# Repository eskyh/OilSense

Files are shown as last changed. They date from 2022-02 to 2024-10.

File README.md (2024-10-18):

## Home Cloud-based Smart Heating Oil Monitoring and Ordering Decision System

This project developed a smart IoT system that combines a **Raspberry Pi Zero** as the central home cloud server (Running **Node-RED** and **MQTT** broker) with distributed smart **ultrasonic sensors** (based on the **D1 Mini-ESP8266**) to monitor home heating oil levels. The system sends alerts to your phone when oil levels drop below a set threshold and features **one-button oil ordering** from the best available deal in the marketplace. This star architecture can be easily extended to other smart home applications, such as sump pit water level monitoring, as shown in Figure 1.

                                            **Figure 1. System architecture**   

System Architecture

## 1. Dashboard and Node-RED Workflow

The Node-RED data flows consist of two components outlined below. They are rendered as dashboards that are accessible on your phone from anywhere (**NOTE**: Port forwarding needs to be configured in the home router!).

1. **Oil Level Monitoring**: This includes oil level monitoring, data management, and dashboard functionalities. Check out the dashboard demonstration in Figure 2 and the simplified worflow (for convenience of demonstration) behind the scene in Figure 4 and 5.

2. **Oil Marketplace and Ordering**: This covers the oil price marketplace and ordering functionalities. See the dashboard demonstration in Figure 3 and the simplified workflow behind the scene in Figure 6.

                           **Figure 2. Oil level monitoring dashboard.**

Oil level monitoring dashboard

                                    **Figure 3. Oil Marketplace and ordering dashboard**

Heating oil marketplace and ordering dashboard

                    **Figure 4. Sensor data processing workflow in Node-RED**

Sensor data processing workflow in Node-RED

`1. Receive sensor measurement data messages from the subscribed MQTT broker.`
`2. Apply filtering algorithms (Median, Kalman Filter, and EWMA) to the measurements.`
`3. Calculate the heating oil level in the tank based on the distance measured from the top of the tank to the oil surface.`
`4. Only pass messages if the change in measurement exceeds a specified threshold.`
`5. Display the oil level and historical data, including daily consumption, on the dashboard.`
`6. Save oil level data to a file.`
`7. Trigger an alarm and send a notification to mobile devices via Telegram bot.`
`8. Toggle notifications on or off via Telegram messages or from the dashboard on mobile.`
`9. Display diagnostic information and environmental data (temperature and humidity) on the dashboard.`

                                            **Figure 5. Actuator workflow in Node-RED**
Actuator workflow in Node-RED

`1. Receive heartbeat, commands, and information messages from the subscribed MQTT broker.`
`2. Display configuration controls for MCU devices (e.g., toggle LED on/off, enable/disable automatic measurement, set measurement intervals, select data filters, enable/disable sensors, trigger a one-time measurement, restart the smart sensor, etc.`
`3. Publish configuration options as retained messages to the MQTT broker, so all subscribed smart sensors will automatically configure themselves based on these settings.`
`4. Publish acturator MQTT messages, so all subscribed smart sensors will execute the corresponding actions.`

                                            **Figure 6. Marketplace workflow in Node-RED**
Marketplace workflow in Node-RED

`1. Collect the real-time futures data.`
`2. Collect real-time local marketplace quotes.`
`3. Dashboard controls and charts showing prices.`
`4. Same as 2 but for another city.`
`5. Set order type (cash/credit) and order amount.`
`6. Construct order with preset form fields and placing order.`

## 2. Source Code Structure

[**`/gauge/src/`**](https://github.com/eskyh/OilSense/tree/main/gauge/src)

[`main.cpp`](https://github.com/eskyh/OilSense/tree/main/gauge/src/main.cpp): The main function of **D1 Mini (ESP8266)** microcontroller firmware. It calls `EspClient` class to do the following works:

`setup()` : Executed once at the start of the program, this phase is typically used for configuration and hardware initialization. Invoke `EspClient::setup()` to load configurations, establish WiFi/MQTT/OTA connections, initialize sensors, and sync time with the NTP server.

`loop()` : Executed repeatedly (hence the name 'loop'). Invoke `EspClient::loop()` to do sensor measurements, MQTT subscribing/publishing messages, processing MQTT actuator commands, managing the web portal, uploading firmware via WiFi, and restarting the device.

[**`/myLibs/network/`**](https://github.com/eskyh/OilSense/tree/main/myLibs/network)

[`EspClient.hpp`](https://github.com/eskyh/OilSense/tree/main/myLibs/network/EspClient.hpp), [`EspClient.cpp`](https://github.com/eskyh/OilSense/tree/main/myLibs/network/EspClient.cpp): The primary class responsible for managing all functions in the firmware and is designed as a singleton.

[`JTimer.h`](https://github.com/eskyh/OilSense/tree/main/myLibs/network/JTimer.h), [`JTimer.cpp`](https://github.com/eskyh/OilSense/tree/main/myLibs/network/JTimer.cpp): Designed to provide an efficient timing mechanism within the firmware. It simplifies the management of timed events and callbacks and is designed as a singleton.

[`Config.hpp`](https://github.com/eskyh/OilSense/tree/main/myLibs/network/Config.hpp), [`Config.cpp`](https://github.com/eskyh/OilSense/tree/main/myLibs/network/Config.cpp) : Managing configuration settings in a JSON format.

EspClient class diagram

JTimer class diagram

[**`/myLibs/sensors/`**](https://github.com/eskyh/OilSense/tree/main/myLibs/sensors)

[`sensor.hpp`](https://github.com/eskyh/OilSense/tree/main/myLibs/sensors/sensor.hpp), [`sensor.cpp`](https://github.com/eskyh/OilSense/tree/main/myLibs/sensors/sensor.cpp): The base **Sensor** calss for other derived sensors below:

- [`sr04.hpp`](https://github.com/eskyh/OilSense/tree/main/myLibs/sensors/sr04.hpp), [`sr04.cpp`](https://github.com/eskyh/OilSense/tree/main/myLibs/sensors/sr04.cpp): Ultrasonic range sensor class for the HC-SR04.

- [`dht11.hpp`](https://github.com/eskyh/OilSense/tree/main/myLibs/sensors/dht11.hpp), [`dht11.cpp`](https://github.com/eskyh/OilSense/tree/main/myLibs/sensors/dht11.cpp): Temperature and humidity sensor class for DHT11.

- [`vl53l0x.hpp`](https://github.com/eskyh/OilSense/tree/main/myLibs/sensors/vl53l0x.hpp), [`vl53l0x.cpp`](https://github.com/eskyh/OilSense/tree/main/myLibs/sensors/vl53l0x.cpp): Infrared distance sensor class for VL53L0X.

[`filter.hpp`](https://github.com/eskyh/OilSense/tree/main/myLibs/sensors/filter.hpp), [`filter.cpp`](https://github.com/eskyh/OilSense/tree/main/myLibs/sensors/filter.cpp): Data filtering algorithm classes: **Median**, **Kalman**, **EWMA**.

[`band.hpp`](https://github.com/eskyh/OilSense/tree/main/myLibs/sensors/band.hpp), [`band.cpp`](https://github.com/eskyh/OilSense/tree/main/myLibs/sensors/band.cpp):  Band filter class supporting both dead band and narrow band.

The **`Sensor`** base class encapsulates common functionalities shared across all sensor types, such as:

* `_read()`: A pure virtual function that each derived sensor class implements to handle sensor-specific reading logic.  
* `setFilter()`: Allows the assignment of a filter (e.g., Median, Kalman, EWMA) to process sensor data.  
* `setMqtt()`: Set MQTT client for data transmission.  
* `getPayload()`: A pure virtual function that is implemented by each derived class to format the sensor's data for transmission.  
* `sendMeasure()`: A method that handles data communication or publication to an MQTT broker or other destinations.

Sensor class diagram

[**`/gauge/web/`**](https://github.com/eskyh/OilSense/tree/main/gauge/web)

[`main.html`](https://github.com/eskyh/OilSense/tree/main/gauge/web/main.html) : A lightweight, all-in-one web portal developed for smart sensor management on D1 Mini. Users can configure settings and perform firmware upgrades over Wi-Fi. This file relies on the following JavaScript and CSS code.

[`espman.js`](https://github.com/eskyh/OilSense/tree/main/gauge/web/espman.js) :  JavaScript code provides the following functions for the web portal: AJAX-based retrieving/updating smart sensor configuration using JSON, adding/removing sensors, pin configurations, file management, firmware uploads, and device restarts.

[`filedrag.js`](https://github.com/eskyh/OilSense/tree/main/gauge/web/filedrag.js) :JavaScript code enabling drag-and-drop functionality on the *File Management* page of the web portal.

[`style.css`](https://github.com/eskyh/OilSense/tree/main/gauge/web/style.css) : The stylesheet for the web portal.

[`release.bat`](https://github.com/eskyh/OilSense/tree/main/gauge/web/release.bat) : A batch command file compresses the `main.html` and all supporting script files into a single HTML, then gzips it. This significantly improves web portal access performance.

[`/config/`](https://github.com/eskyh/OilSense/tree/main/gauge/web/config) :  This subfolder contains three sample configuration JSON files.

                                    **Figure 7. Web portal for Microcontroller**

Web portal for smart sensor

[**`/tools/`**](https://github.com/eskyh/OilSense/tree/main/tools)

[`index.html`](https://github.com/eskyh/OilSense/tree/main/tools/index.html): A web-based tool I developed to display multi-time series data (e.g., oil level data from `data.series.csv`) or marketplace quotes from various dealers (e.g., `data.quotes.csv` as shown below).

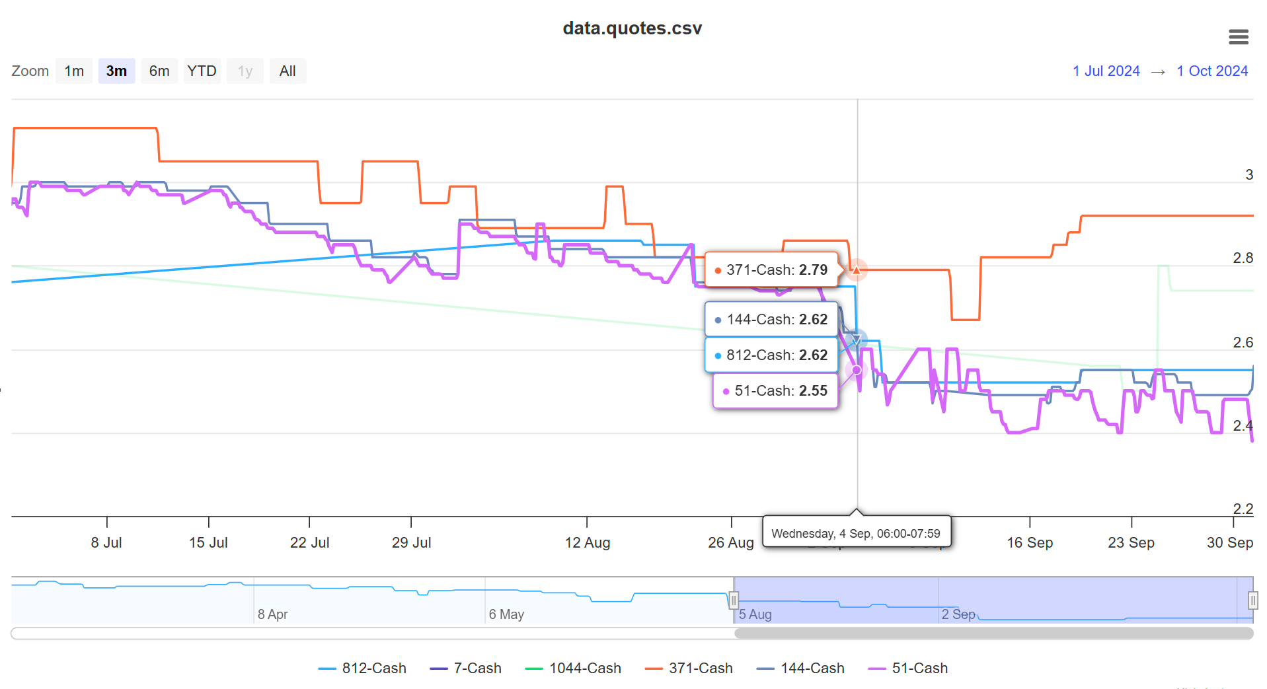
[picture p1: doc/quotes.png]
Marketplace quotes chart


[**`/gauge/3d_model/`**](https://github.com/eskyh/OilSense/tree/main/gauge/3d_model)

A series of 3D model of internal structural components designed to support the D1 Mini and connected sensors. `model_final_subtract.3mf` is the final design, while the others are either intermediate versions or older designs where the sensor seat location caused interference with the housing.

3D design model

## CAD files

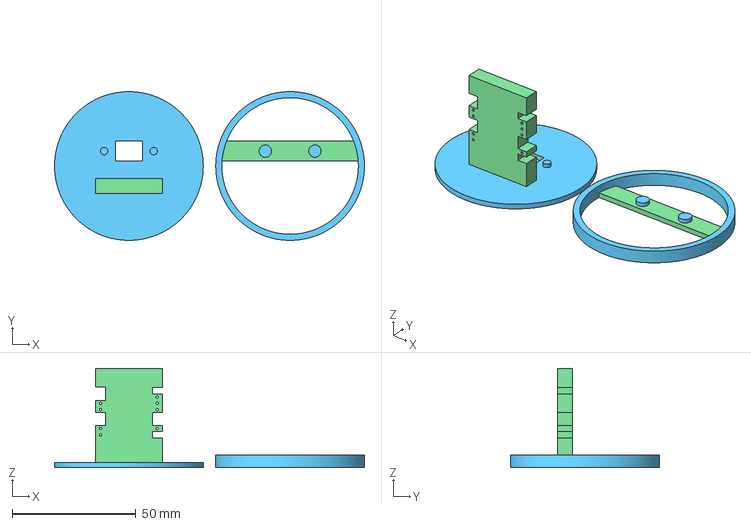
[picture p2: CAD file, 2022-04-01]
gauge/3d_model/model_laser_subtracted.3mf
125.0 x 60.0 x 40.0 mm

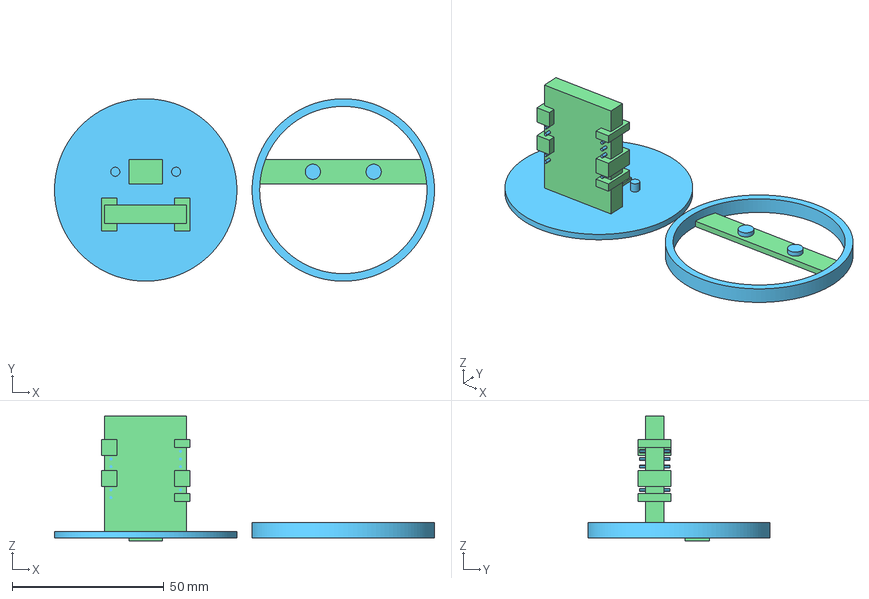
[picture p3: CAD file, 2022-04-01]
gauge/3d_model/model_laser.3mf
125.0 x 60.0 x 41.0 mm

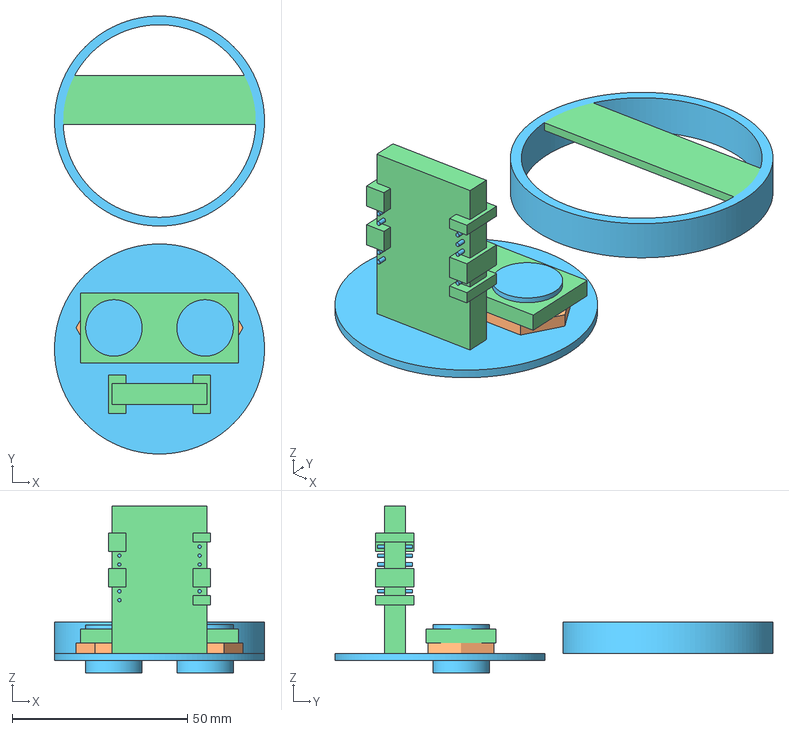
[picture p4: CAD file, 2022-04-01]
gauge/3d_model/model_final.3mf
59.9 x 124.9 x 47.5 mm

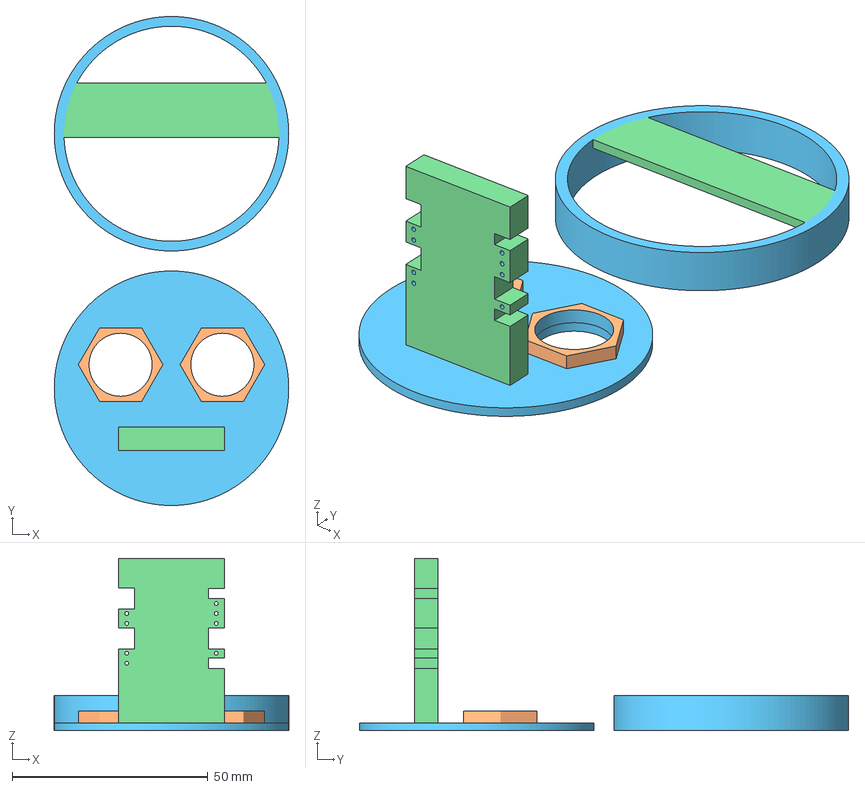
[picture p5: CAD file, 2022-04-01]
gauge/3d_model/model_final_subtract.3mf
59.9 x 124.9 x 44.0 mm

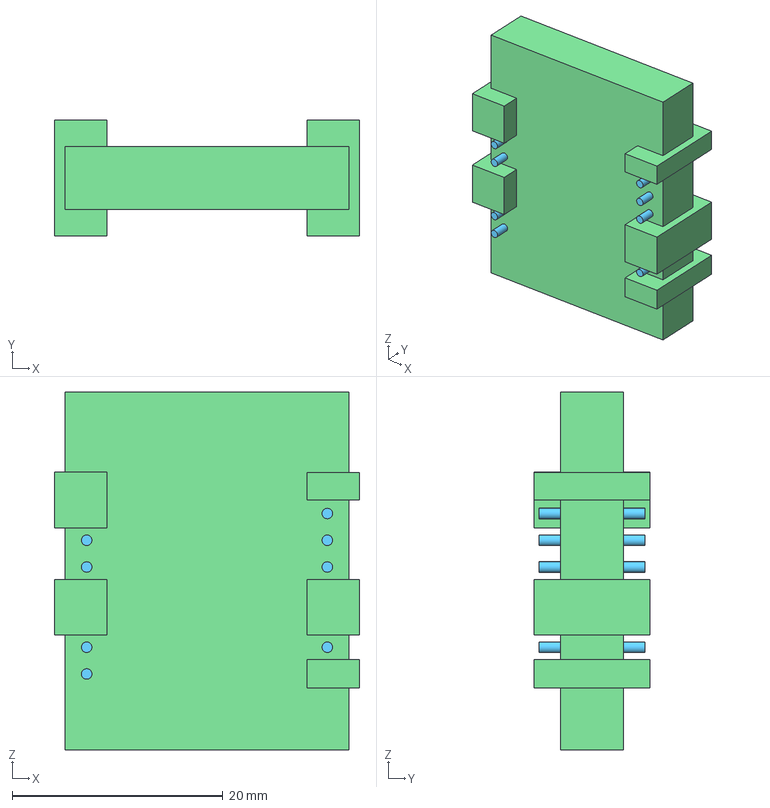
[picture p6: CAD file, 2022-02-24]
gauge/3d_model/breadboard.3mf
29.0 x 11.0 x 34.0 mm

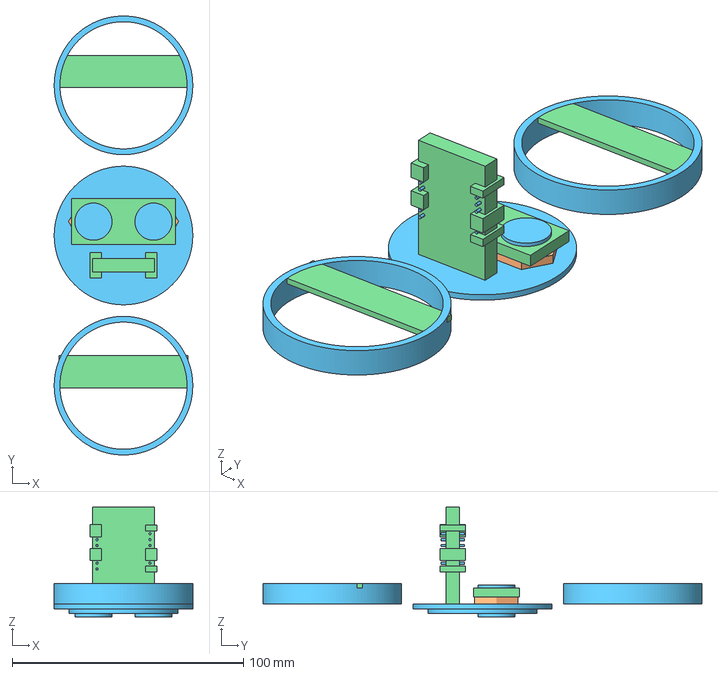
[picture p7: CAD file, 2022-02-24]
gauge/3d_model/model.3mf
60.0 x 190.0 x 47.5 mm

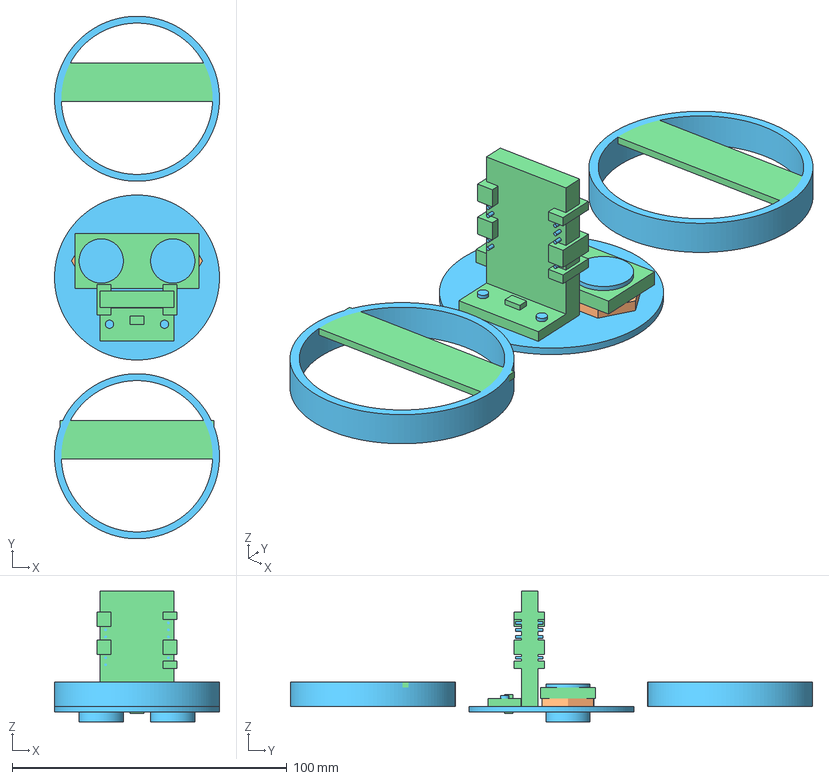
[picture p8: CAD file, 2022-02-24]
gauge/3d_model/model_dual.3mf
60.0 x 190.0 x 47.5 mm

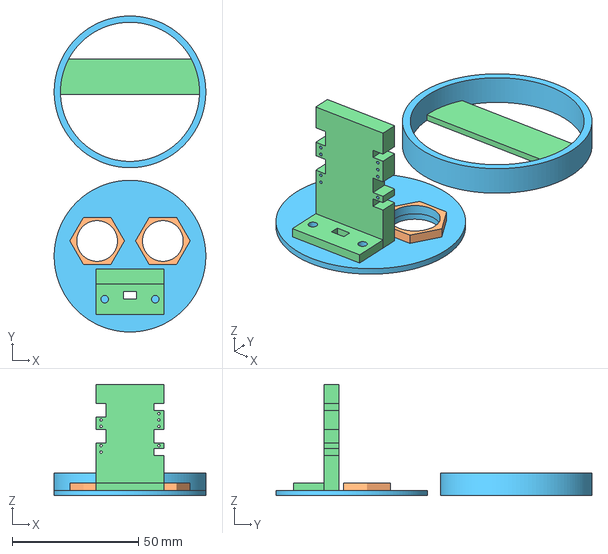
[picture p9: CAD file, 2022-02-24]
gauge/3d_model/model_dual_subtracted.3mf
60.0 x 125.0 x 44.0 mm

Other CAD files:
gauge/3d_model/model_subtracted.3mf
gauge/3d_model/model_dual_subtracted.stl
gauge/3d_model/model_final_subtract.stl
gauge/3d_model/model_laser_subtracted.stl
gauge/3d_model/model_subtracted.stl

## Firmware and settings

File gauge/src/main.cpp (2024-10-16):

#include <Arduino.h>
#include "EspClient.hpp"

// Create a singleton instance of EspClient.
EspClient &espClient = EspClient::instance();

void setup()
{
    //-- Initialize MCU Pins and Serial speed

    // Initialize digital pin LED_BUILTIN as an output (used as ESP heartbeat indicator).
    pinMode(LED_BUILTIN, OUTPUT);
    // Turn the LED on (LOW) or off (HIGH) as needed. (NOTE: It is inverted.)
    digitalWrite(LED_BUILTIN, HIGH);

    //-- Serial Communication baudrate options: 9600, 115200, 250000
    Serial.begin(115200);

    //-- EspClient config and connection establishment:
    //   WiFi, MQTT, OTA, Init Sensors, etc.
    espClient.setup();
}

void loop()
{
    //-- Run EspClient tasks:
    // sensor measurement and publishing, web portal handling,
    // actuator MQTT commands, and Wi-Fi/MQTT reconnections.
    espClient.loop();
}

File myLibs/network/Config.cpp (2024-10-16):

#include "Config.hpp"
#include <LittleFS.h>

#define MAX(x, y) (((x) > (y)) ? (x) : (y))
#define MIN(x, y) (((x) < (y)) ? (x) : (y))

Config &Config::instance()
{
    static Config _instance;
    return _instance;
}

// Loads the configuration from a file
bool Config::loadConfig(const char *filename)
{
    if (!LittleFS.begin())
    {
        Serial.println(F("FS: Failed to load json config"));
        return false;
    }

    if (!LittleFS.exists(filename))
    {
        Serial.print(F("FS: File doesn't exist: "));
        Serial.println(filename);
        return false;
    }

    // Open file for reading
    File file = LittleFS.open(filename, "r");

    // Deserialize the JSON document
    DeserializationError error = deserializeJson(doc, file);
    if (error)
        Serial.println(F("Failed to read file, using default configuration"));

    // Module name
    module = doc["module"].as<String>();
    Serial.printf("MODULE %s\n", module.c_str()); // module name, used as mqttClientName, otaHost

    // Wifi
    ssid = doc["wifi"]["ssid"].as<String>();
    pass = doc["wifi"]["pass"].as<String>();
    ip = doc["ip"].as<String>();
    gateway = doc["gateway"].as<String>();
    apPass = doc["appass"].as<String>();
    otaPass = doc["otapass"].as<String>();

    // MQTT broker
    mqttServer = doc["mqtt"]["server"].as<String>();
    mqttPort = doc["mqtt"]["port"];
    mqttUser = doc["mqtt"]["user"].as<String>();
    mqttPass = doc["mqtt"]["pass"].as<String>();

    // Close the file
    file.close();

#ifdef _DEBUG
    printFile(filename);
    printConfig();
#endif

    return true;
}

// Saves the configuration to a file
bool Config::saveConfig(const char *filename)
{
    if (!LittleFS.begin())
    {
        Serial.println(F("FS: Failed to load json config"));
        return false;
    }

    // Delete existing file, otherwise it will be appended to the existing one
    if (LittleFS.exists(filename))
        LittleFS.remove(filename);

    // Open file for writing
    File file = LittleFS.open(filename, "w");
    if (!file)
    {
        Serial.println(F("Failed to create file"));
        return false;
    }

    // Serialize JSON to file
    if (serializeJson(doc, file) == 0)
    {
        Serial.println(F("Failed to write to file"));
    }

    // Close the file
    file.close();

#ifdef _DEBUG
    printConfig();
    printFile(filename);
#endif

    return false;
}

#ifdef _DEBUG

void Config::printConfig()
{
    Serial.println(F("----------------------------"));
    Serial.println(F("Configuration"));
    Serial.println(F("----------------------------"));

    serializeJsonPretty(doc, Serial);
    Serial.println();
}

// Prints the content of a file to the Serial
void Config::printFile(const char *filename)
{
    if (!LittleFS.begin())
    {
        Serial.println(F("FS: Failed to load json config"));
        return;
    }

    // Open file for reading
    File file = LittleFS.open(filename, "r");
    if (!file)
    {
        Serial.println(F("Failed to read file"));
        return;
    }

    Serial.println(F("----------------------------"));
    Serial.print(F("File: "));
    Serial.println(filename);
    Serial.println(F("----------------------------"));
    // Extract each characters by one by one
    while (file.available())
    {
        Serial.print((char)file.read());
    }
    Serial.println();
    Serial.println(F("----------------------------"));

    // Close the file
    file.close();
}
#endif

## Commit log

2022-02-24 inital checkin
    [breadboard.3mf, model.3mf, model_dual.3mf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]
2022-02-25 Fixed bugs on string copy...
    [main.cpp]
2022-02-25 HC-SR04: turnoff interrupt so pulseIn() is more accurate.
2022-02-26 Configured MQTT server with authentication/ user/pass. NODE-RED flow need to add user/pass in security tab as well!
2022-02-28 fixed the mqtt connect/disconnect issue. => do not call subscribe directly in mqttConnect event, use timer.
2022-03-01 Enhanced the Wifi/MQTT connection failure issue (need to put it in the main loop). Added the reason (Either Wifi or MQTT connection failure) show up in the portal page.
    [main.cpp]
2022-03-03 update flow
2022-03-03 flow update: use fs library
2022-03-13 use HC-SR04 sensor for sumppit
2022-04-01 archive models
    [model_final.3mf, model_final_subtract.3mf, model_final_subtract.stl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]
2022-04-28 Changed to static IP avoid the WiFi connection issue
    [sr04.cpp]
2022-12-02 updated: 1) Usage interval setting (default to 0.5 days) 2) Added deal time series for simulated data from file for cash heating oil
2022-12-12 update sensor code.
2022-12-17 update the flow with auto adjusted interval.
2022-12-28 Fixed OTA setup missing issue.
    [EspClient.cpp]
2022-12-28 fix OTA name issue. (OTA is using mDNS, so no need start mDNS to use the name. and Do NOT end either).
    [EspClient.cpp, EspClient.hpp]
2022-12-30 Enhanced EspClient and sensor classes
2022-12-30 update sensor pointer issue
    [Config.cpp, EspClient.cpp]
2022-12-30 unifiy codes
    [breadboard.3mf, model.3mf, model_dual.3mf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]
2022-12-31 fixed bug of buildjson in config, added empty option in sensor dropdown list in index.html
    [Config.cpp]
2023-01-01 Change close portal with only switch root response listener. Update files from web OTA always on.
2023-01-05 missing dh11 sensor config
2024-10-16 Refactored the timer class to avoid memory issues.
    [EspClient.cpp, EspClient.hpp, main.cpp]
2024-10-16 Switch to new web page (no JsonEditor).
2024-10-16 corrected the PIN value definition in espman.js
2024-10-16 added drag & drop files. real-time config json string display. fixed some bugs.
    [EspClient.cpp]
2024-10-16 Updated for working with ESP32-CAM
2024-10-16 added some other ESP board
2024-10-16 Solved the 8266 Wifi not connecting issue by
    WiFi.setPhyMode(WIFI_PHY_MODE_11G);
    [Config.cpp, EspClient.cpp, EspClient.hpp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]
2024-10-16 1. Added timestamp from sensor measurement 2. Backup latest flow.json
2024-10-16 !! Node-RED flow update: First successful oil order placed from the flow dashboard! (CashHeatingOil.com)
2024-10-16 Move the web-based data chart tool to this folder
    [data.test.csv]
2024-10-16 update data
    [data.series.csv, data.test.csv]
2024-10-16 Minor update to the Node-RED flows.json for tooltips and labels.
2024-10-18 Added some Node-RED dashboard and work flow pictures to the end of front page - README.md.
